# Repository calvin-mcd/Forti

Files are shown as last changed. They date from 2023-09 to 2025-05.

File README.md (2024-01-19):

# Førti

The Førti pcb (40 in Norwegian) is a 13u 40% pcb with full basekit support for the upcoming Førti keyboard case created and designed by xonuss and xezioh that is based on [Geon's F1-8x](https://geon.works/pages/f1-8x). The pcb takes its layout and design cues from the [oxymoron](https://imgur.com/a/UKyKxDe), [bully](https://www.cbkbd.com/product/bully) and [ttocyobitna](https://trashman.wiki/keyboards/ttocyobitna) amongst others. It's a stm32 based pcb for low cost, good performance.

## Layout

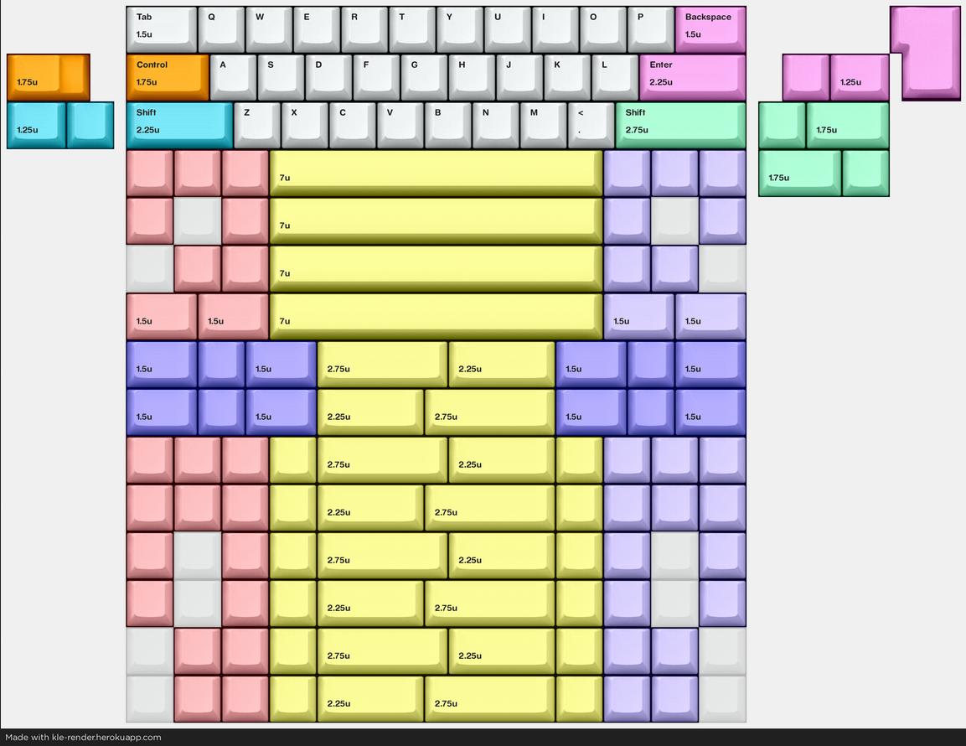
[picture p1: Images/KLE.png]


[Link](http://www.keyboard-layout-editor.com/#/gists/abf1199a554d2e1b5c349f9fdb908042)

## Case

WIP, design by xonuss

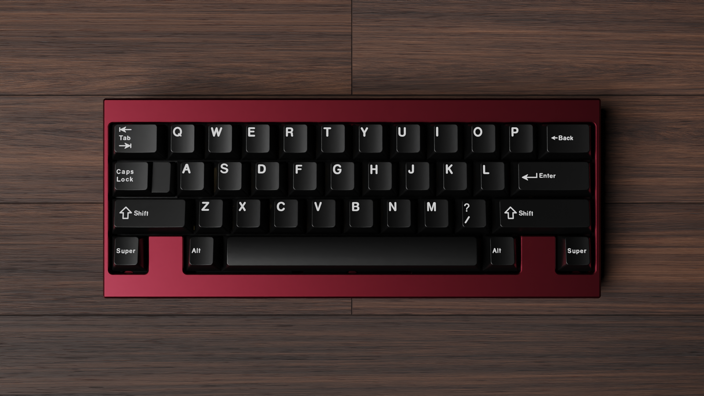
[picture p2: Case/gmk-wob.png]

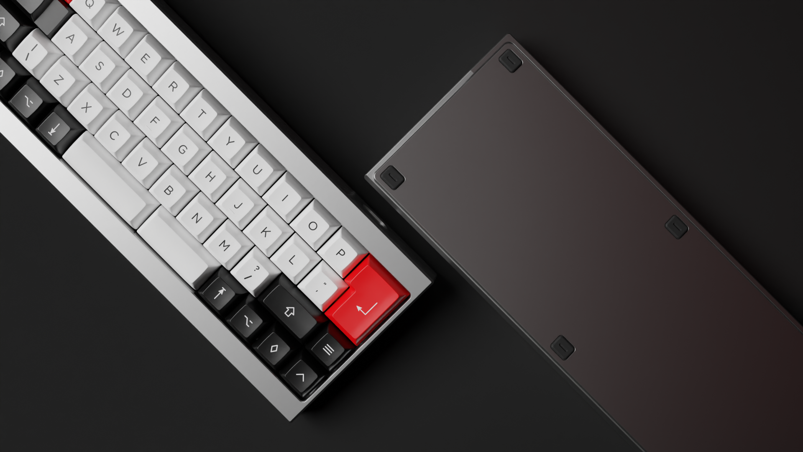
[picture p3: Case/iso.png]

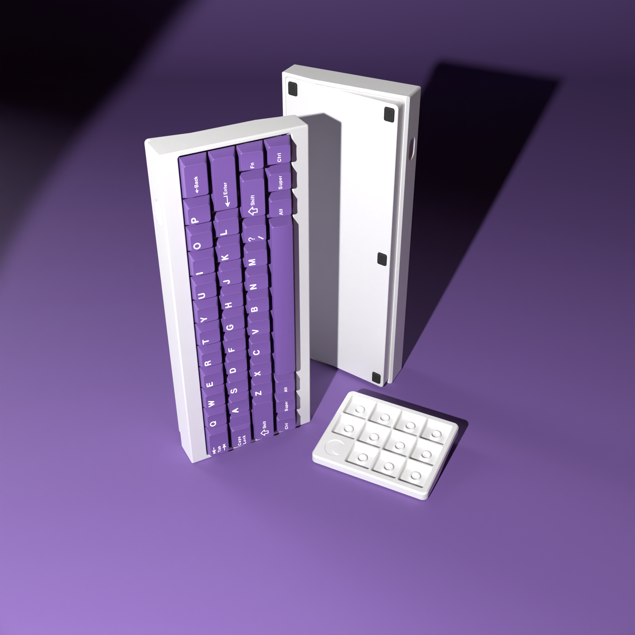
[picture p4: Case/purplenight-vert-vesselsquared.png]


## Todo

- [X] order & test pcb
- [X] create firmware
- [X] order & test case
- [ ] revise mx pcb
- [ ] create HS & EC pcbs (work-in-progress)

## Disclaimer

Please note that this project is a work in progress with no guarantees of a working outcome. No-one involved in this project is responsible for any usage issues that may arise. However, feel free to edit, modify and otherwise utilise these files.

## License

Shield: 

This work is licensed under a  
[Creative Commons Attribution-NonCommercial-ShareAlike 4.0 International License](http://creativecommons.org/licenses/by-nc-sa/4.0/).



## Credits

Big thanks to xonuss and xezioh for letting me join this awesome collaboration!	

As always big thanks to the many people who helped and inspired this board!

Any questions, contact Calvin0563 on Discord.

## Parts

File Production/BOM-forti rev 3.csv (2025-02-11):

Comment | Designator | Footprint | LCSC | Quantity
SKQGABE010 | SW1 | SW_SPST_SKQG_WithoutStem | C115351 | 1
100nF | C4,C5,C6,C7,C8,C9 | C_0603_1608Metric | C14663 | 6
5k1 | R1,R2 | R_0603_1608Metric | C14677 | 2
1uF | C1,C2 | C_0603_1608Metric | C15849 | 2
USB_C_Receptacle_USB2.0 | J1 | USB_C_Receptacle_HRO_TYPE-C-31-M-12 | C165948 | 1
10k | R3 | R_0603_1608Metric | C2139679 | 1
USBLC6-2SC6 | U1 | SOT-23-6 | C2827654 | 1
XC6206PxxxMR-Regulator_Linear | U3 | SOT-23 | C5446 | 1
D_Small | D1,D10,D11,D12,D13,D14,D15,D16,D17,D18,D19,D2,D20,D21,D22,D23,D24,D25,D26,D27,D28,D29,D3,D30,D31,D32,D33,D34,D35,D36,D37,D38,D39,D4,D40,D41,D42,D43,D44,D45,D46,D47,D5,D6,D7,D8,D9 | D_SOD-123F | C64898 | 47
500mA | F1 | Fuse_1206_3216Metric | C70076 | 1
SMF9.0CA | D_PWR1 | D_SOD-123 | C707469 | 1
STM32F072C8Tx | U2 | LQFP-48_7x7mm_P0.5mm | C80488 | 1
10uF | C3 | C_0603_1608Metric | C96446 | 1

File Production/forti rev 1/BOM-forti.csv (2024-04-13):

Comment | Designator | Footprint | LCSC
SKQGABE010 | SW1 | SW_SPST_SKQG_WithoutStem | C115351
100nF | C10,C4,C5,C6,C7,C8,C9 | C_0603_1608Metric | C14663
5k1 | R1,R2 | R_0603_1608Metric | C14677
1uF | C1,C2 | C_0603_1608Metric | C15849
USB_C_Receptacle_USB2.0 | J1 | USB_C_Receptacle_HRO_TYPE-C-31-M-12 | C165948
10k | R3 | R_0603_1608Metric | C2139679
USBLC6-2SC6 | U1 | SOT-23-6 | C2827654
XC6206PxxxMR-Regulator_Linear | U3 | SOT-23 | C5446
D_Small | D1,D10,D11,D12,D13,D14,D15,D16,D17,D18,D19,D2,D20,D21,D22,D23,D24,D25,D26,D27,D28,D29,D3,D30,D31,D32,D33,D34,D35,D36,D37,D38,D39,D4,D40,D41,D42,D43,D44,D45,D46,D47,D5,D6,D7,D8,D9 | D_SOD-123F | C64898
500mA | F1 | Fuse_1206_3216Metric | C70076
SMF9.0CA | D_PWR1 | D_SOD-123 | C707469
74AHCT1G125 | U4 | TSOT-23-5 | C7468
STM32F072C8Tx | U2 | LQFP-48_7x7mm_P0.5mm | C80488
10uF | C3 | C_0603_1608Metric | C96446
WS2812_2020 | LED1,LED10,LED11,LED12,LED13,LED14,LED15,LED16,LED17,LED18,LED2,LED3,LED4,LED5,LED6,LED7,LED8,LED9 | LED_WS2812_2020 | C965555

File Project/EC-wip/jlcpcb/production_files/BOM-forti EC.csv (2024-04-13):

Comment | Designator | Footprint | LCSC
1k | R23 | R_0402_1005Metric | C11702
STM32F401CBUx | U8 | QFN-48-1EP_7x7mm_P0.5mm_EP5.6x5.6mm | C118825
100nF | C12 | C_0603_1608Metric | C14663
1uF | C1 | C_0603_1608Metric | C14664
5k1 | R1,R2 | R_0603_1608Metric | C14677
220pF NP0 | C4 | C_0402_1005Metric | C1530
USB_C_Receptacle_USB2.0 | J2 | USB_C_Receptacle_HRO_TYPE-C-31-M-12 | C165948
4.7u | C16 | C_0402_1005Metric | C23733
100 | R19,R20,R21,R22 | R_0402_1005Metric | C25076
100k | R11,R12,R13,R14,R15,R16,R17,R18,R4,R5,R6,R7,R8,R9 | R_0402_1005Metric | C25741
10k | R24,R25,R27 | R_0402_1005Metric | C25744
USBLC6-2SC6 | U1 | SOT-23-6 | C2827654
100n | C10,C15,C17,C18,C19,C20,C21,C3 | C_0402_1005Metric | C307331
OPA354 | U3 | SOT-23-5 | C36384
1uF | C2,C22 | C_0603_1608Metric | C52923
XC6206PxxxMR-Regulator_Linear | U2 | SOT-23 | C5446
74HC4051 | U5,U7 | TSSOP16 | C5645
500mA | F1 | Fuse_1206_3216Metric | C70076
SMF9.0CA | D_PWR1 | D_SOD-123 | C707469
74AHCT1G125 | U4 | TSOT-23-5 | C7468
8 MHz | Y1 | Resonator_SMD_Murata_CSTxExxV-3Pin_3.0x1.1mm | C907975
WS2812_2020 | LED1,LED15,LED16,LED17,LED18,LED19,LED2,LED20,LED21,LED22,LED23,LED24,LED25,LED26,LED27,LED3,LED30,LED31 | LED_WS2812_2020 | C965555

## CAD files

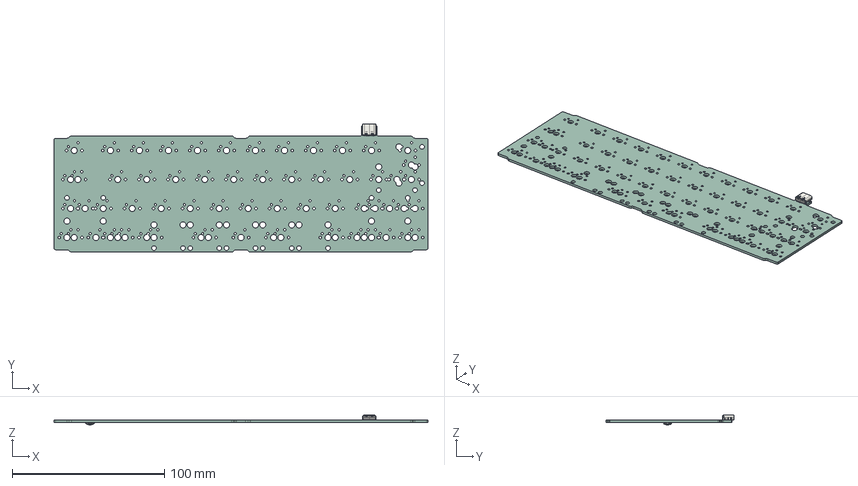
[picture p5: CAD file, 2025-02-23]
Project/forti rev 3.step
245.7 x 84.1 x 6.55 mm
USB_C_Receptacle_16P_TopMnt_Horizontal_GCT_USB4105-xx-A
SW_SPST_TL3342
forti rev 3_PCB

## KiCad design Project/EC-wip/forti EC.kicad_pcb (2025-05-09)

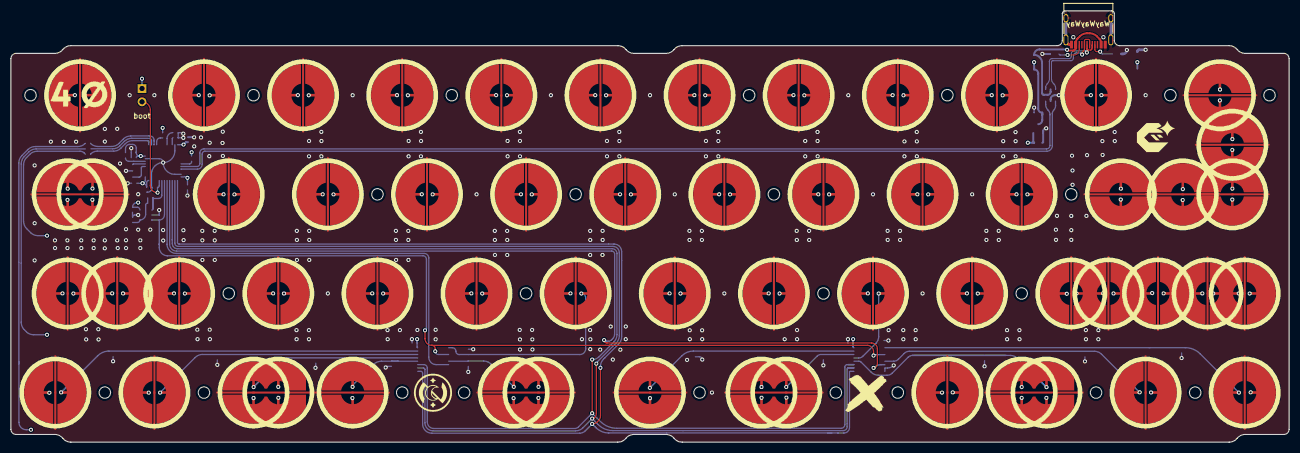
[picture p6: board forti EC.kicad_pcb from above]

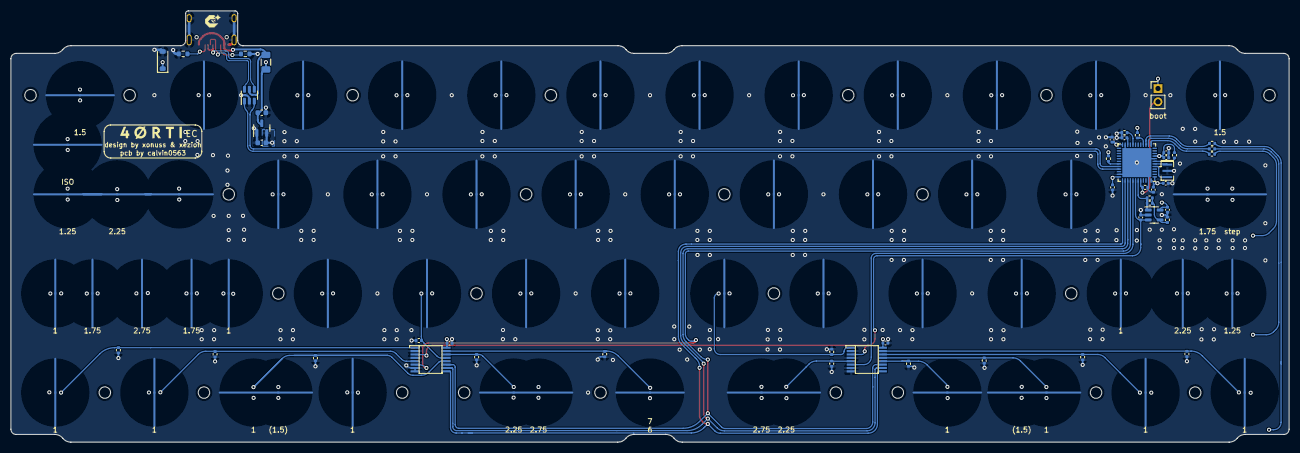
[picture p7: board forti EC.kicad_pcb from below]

Board: 4 copper layers, 245.7 x 82.9 mm, 124 parts (48 on the bottom side), 45 nets.

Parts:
C1, C2: 1uF; C_0603_1608Metric
C3, C10, C15, C17, C18, C19, C20, C21: 100n; C_0402_1005Metric
C4: 220pF NP0; C_0402_1005Metric
C16: 4.7u; C_0402_1005Metric
C22: 1u; C_0402_1005Metric
D_PWR1: SMF9.0CA; D_SOD-123
F1: 500mA; Fuse_1206_3216Metric
H1, H2, H3, H4, H5, H6, H7, H8, H9, H10, H11, H12, H13, H14, H15, H16, H17, H18, H19, H20, H21, H22, H23, H24: MountingHole; HOLE_M2
J2: USB_C_Receptacle_USB2.0; USB_C_Receptacle_HRO_TYPE-C-31-M-12
R1, R2: 5k1; R_0603_1608Metric
R4, R5, R6, R7, R8, R9, R11, R12, R13, R14, R15, R16, R17, R18: 100k; R_0402_1005Metric
R19, R20, R21, R22: 100; R_0402_1005Metric
R23: 1k; R_0402_1005Metric
R24, R25, R27: 10k; R_0402_1005Metric
R26: DNP; R_0402_1005Metric
SW1: BOOT0; PinHeader_1x02_P2.54mm_Vertical
SW_EC1, SW_EC2, SW_EC3, SW_EC4, SW_EC5, SW_EC6, SW_EC7, SW_EC8, SW_EC9, SW_EC10, SW_EC11, SW_EC12, SW_EC14, SW_EC15, SW_EC16, SW_EC17, SW_EC18, SW_EC19, SW_EC20, SW_EC21, SW_EC22, SW_EC24, SW_EC25, SW_EC26, SW_EC27, SW_EC28, SW_EC29, SW_EC30, SW_EC31, SW_EC32, SW_EC33, SW_EC34, SW_EC50: Topre; ecs_pad_1U_no_ring
SW_EC13: stepped; ecs_pad_no_ring_stepped&normal
SW_EC23: Topre; ecs_pad_1U_no_ring_1u_edge_cut
SW_EC35, SW_EC36: 1u, 175u; ecs_pad_no_ring_1u1.75u
SW_EC37, SW_EC38, SW_EC40, SW_EC44, SW_EC46, SW_EC47: 1u; ecs_pad_1U_no_ring
SW_EC39, SW_EC45: stepped; ecs_pad_no_ring_stepped&normal_cut
SW_EC41, SW_EC43: split; ecs_pad_no_ring_stepped&normal
SW_EC42: 6u 7u; ecs_pad_1U_no_ring
SW_EC48: ISO; ecs_pad_1U_no_ring
SW_EC49: ansi; ecs_pad_1U_no_ring_1u_edge_cut
SW_EC52: 275u; ecs_pad_1U_no_ring
U1: USBLC6-2SC6; SOT-23-6
U2: XC6206PxxxMR-Regulator_Linear; SOT-23
U3: OPA354; SOT-23-5
U5, U7: 74HC4051; TSSOP16
U8: STM32F401CBUx; QFN-48-1EP_7x7mm_P0.5mm_EP5.6x5.6mm
Y1: 8 MHz; Resonator_SMD_Murata_CSTxExxV-3Pin_3.0x1.1mm

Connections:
+5V: C1.2, D_PWR1.1 (A1), F1.2, U2.3 (VI)
/CC1: J2.A5 (CC1), R1.1
/CC2: J2.B5 (CC2), R2.1
ADC: R6.1, R26.1, U3.1, U8.43 (PB7)
AMUX_SEL_0: U5.11 (S0), U7.11 (S0), U8.39 (PB3)
AMUX_SEL_1: U5.10 (S1), U7.10 (S1), U8.38 (PA15)
AMUX_SEL_2: U5.9 (S2), U7.9 (S2), U8.37 (PA14)
APLEX_EN_PIN_0: U5.6 (~E), U8.41 (PB5)
APLEX_EN_PIN_1: U7.6 (~E), U8.40 (PB4)
APLEX_OUT_PIN_0: C4.1, U3.3 (+), U5.3 (A), U7.3 (A), U8.42 (PB6)
BOOT0: R27.1, SW1.2 (B), U8.44 (BOOT0)
BOOT1: R25.2, U8.20 (PB2)
COL0: R7.1, SW_EC1.1, SW_EC13.1, SW_EC25.1, SW_EC37.1, SW_EC50.1, U5.15 (A2)
COL1: R5.1, SW_EC2.1, SW_EC14.1, SW_EC26.1, SW_EC38.1, U5.14 (A1)
COL2: R4.1, SW_EC3.1, SW_EC15.1, SW_EC27.1, SW_EC39.2, U5.13 (A0)
COL3: R8.1, SW_EC4.1, SW_EC16.1, SW_EC28.1, SW_EC40.1, U5.12 (A3)
COL4: R18.1, SW_EC5.1, SW_EC17.1, SW_EC29.1, SW_EC41.1, U5.5 (A5)
COL5: R9.1, SW_EC6.1, SW_EC18.1, SW_EC30.1, U5.1 (A4)
COL6: R13.1, SW_EC7.1, SW_EC19.1, SW_EC31.1, SW_EC42.1, U7.15 (A2)
COL7: R12.1, SW_EC8.1, SW_EC20.1, SW_EC32.1, SW_EC43.1, U7.14 (A1)
COL8: R11.1, SW_EC9.1, SW_EC21.1, SW_EC33.1, SW_EC44.1, U7.13 (A0)
COL9: R14.1, SW_EC10.1, SW_EC22.1, SW_EC34.1, SW_EC45.2, U7.12 (A3)
COL10: R16.1, SW_EC11.1, SW_EC23.2, SW_EC35.2, SW_EC46.1, U7.5 (A5)
COL11: R15.1, SW_EC12.1, SW_EC24.1, SW_EC36.1, SW_EC36.3, SW_EC47.1, SW_EC48.1, SW_EC49.1, SW_EC52.2, U7.1 (A4)
D_N: U1.3 (I/O2), U8.32 (PA11)
D_P: U1.1 (I/O1), U8.33 (PA12)
D_USB_N: J2.A7 (D-), J2.B7 (D-), U1.4 (I/O2)
D_USB_P: J2.A6 (D+), J2.B6 (D+), U1.6 (I/O1)
GND: C1.1, C2.1, C3.1, C4.2, C10.2, C15.2, C16.2, C17.2, C18.2, C19.2, C20.2, C21.2, C22.2, D_PWR1.2 (A2), J2.A1 (GND), J2.A12 (GND), J2.B1 (GND), J2.B12 (GND), J2.S1 (SHIELD), R1.2, R2.2, R4.2, R5.2, R7.2, R8.2, R9.2, R11.2, R12.2, R13.2, R14.2, R15.2, R16.2, R18.2, R23.2, R25.1, R27.2, SW_EC1.3 (SG), SW_EC2.3 (SG), SW_EC3.3 (SG), SW_EC4.3 (SG), SW_EC5.3 (SG), SW_EC6.3 (SG), SW_EC7.3 (SG), SW_EC8.3 (SG), SW_EC9.3 (SG), SW_EC10.3 (SG), SW_EC11.3 (SG), SW_EC12.3 (SG), SW_EC13.3 (SG), SW_EC14.3 (SG), SW_EC15.3 (SG), SW_EC16.3 (SG), SW_EC17.3 (SG), SW_EC18.3 (SG), SW_EC19.3 (SG), SW_EC20.3 (SG), SW_EC21.3 (SG), SW_EC22.3 (SG), SW_EC23.3 (SG), SW_EC24.3 (SG), SW_EC25.3 (SG), SW_EC26.3 (SG), SW_EC27.3 (SG), SW_EC28.3 (SG), SW_EC29.3 (SG), SW_EC30.3 (SG), SW_EC31.3 (SG), SW_EC32.3 (SG), SW_EC33.3 (SG), SW_EC34.3 (SG), SW_EC35.4 (SG), SW_EC36.4 (SG), SW_EC37.3 (SG), SW_EC38.3 (SG), SW_EC39.3 (SG), SW_EC40.3 (SG), SW_EC41.3 (SG), SW_EC42.3 (SG), SW_EC43.3 (SG), SW_EC44.3 (SG), SW_EC45.3 (SG), SW_EC46.3 (SG), SW_EC47.3 (SG), SW_EC48.3 (SG), SW_EC49.3 (SG), SW_EC50.3 (SG), SW_EC52.3 (SG), U1.2 (GND), U2.1 (GND), U3.2 (V-), U5.2 (A6), U5.4 (A7), U5.7 (VEE), U5.8 (GND), U7.2 (A6), U7.4 (A7), U7.7 (VEE), U7.8 (GND), U8.8 (VSSA), U8.23 (VSS), U8.35 (VSS), U8.47 (VSS), U8.49 (VSS), Y1.2
NRST: R24.2, U8.7 (NRST)
unnamed: R6.2, R23.1, R26.2, U3.4 (-)
unnamed: R19.1, U8.13 (PA3)
unnamed: R20.1, U8.14 (PA4)
unnamed: R21.2, U8.15 (PA5)
unnamed: R22.2, U8.16 (PA6)
unnamed: R17.1, U8.31 (PA10)
unnamed: C16.1, U8.22 (VCAP1)
ROW0: R22.1, SW_EC1.2, SW_EC2.2, SW_EC3.2, SW_EC4.2, SW_EC5.2, SW_EC6.2, SW_EC7.2, SW_EC8.2, SW_EC9.2, SW_EC10.2, SW_EC11.2, SW_EC12.2
ROW1: R19.2, SW_EC13.2, SW_EC14.2, SW_EC15.2, SW_EC16.2, SW_EC17.2, SW_EC18.2, SW_EC19.2, SW_EC20.2, SW_EC21.2, SW_EC22.2, SW_EC23.1, SW_EC24.2, SW_EC48.2, SW_EC49.2
ROW2: R20.2, SW_EC25.2, SW_EC26.2, SW_EC27.2, SW_EC28.2, SW_EC29.2, SW_EC30.2, SW_EC31.2, SW_EC32.2, SW_EC33.2, SW_EC34.2, SW_EC35.1, SW_EC35.3, SW_EC36.2, SW_EC50.2, SW_EC52.1
ROW3: R21.1, SW_EC37.2, SW_EC38.2, SW_EC39.1, SW_EC40.2, SW_EC41.2, SW_EC42.2, SW_EC43.2, SW_EC44.2, SW_EC45.1, SW_EC46.2, SW_EC47.2
VBAT: C2.2, C3.2, C10.1, C15.1, C17.1, C18.1, C19.1, C20.1, C21.1, C22.1, R17.2, R24.1, SW1.1 (A), U2.2 (VO), U3.5 (V+), U5.16 (VCC), U7.16 (VCC), U8.1 (VBAT), U8.9 (VREF+), U8.24 (VDD), U8.36 (VDD), U8.48 (VDD)
VBUS: F1.1, J2.A4 (VBUS), J2.A9 (VBUS), J2.B4 (VBUS), J2.B9 (VBUS), U1.5 (VBUS)
XTAL0: U8.5 (PH0), Y1.3
XTAL1: U8.6 (PH1), Y1.1

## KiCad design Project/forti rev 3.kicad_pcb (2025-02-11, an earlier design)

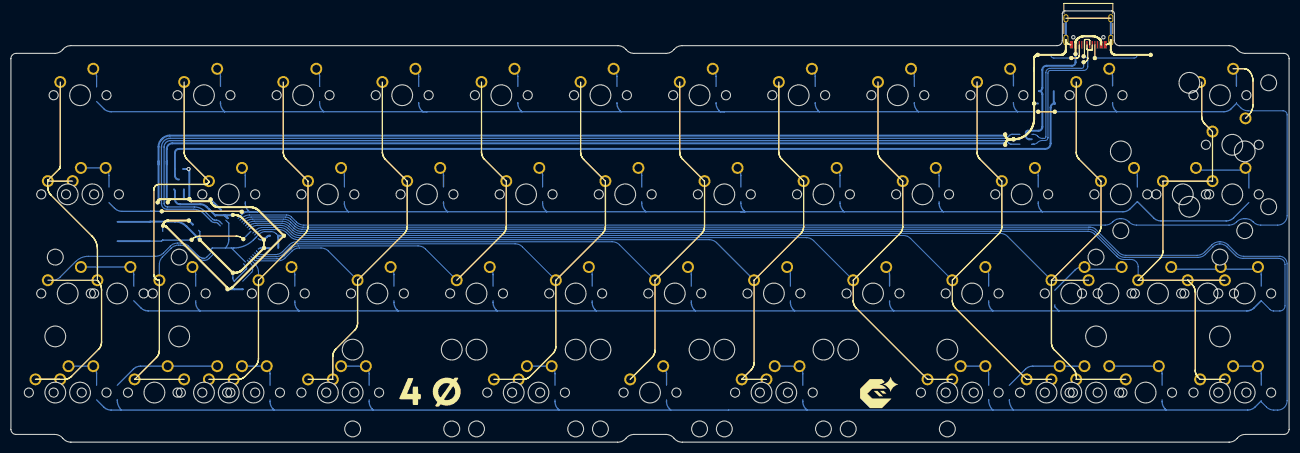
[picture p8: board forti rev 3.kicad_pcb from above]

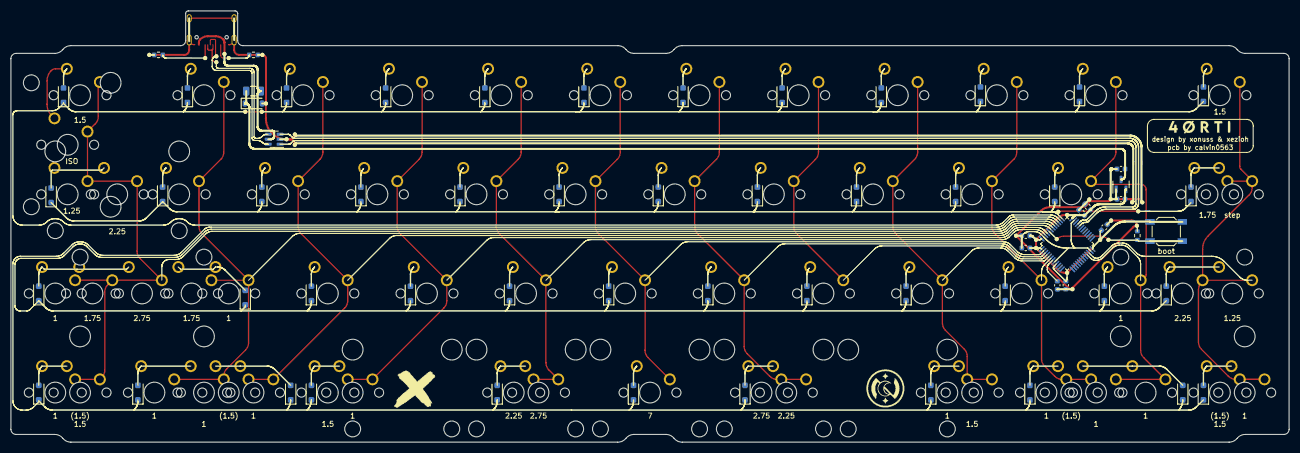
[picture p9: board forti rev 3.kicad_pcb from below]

Board: 2 copper layers, 245.7 x 82.9 mm, 139 parts (65 on the bottom side), 75 nets.

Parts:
C1, C2: 1uF; C_0603_1608Metric
C3: 10uF; C_0603_1608Metric
C4, C5, C6, C7, C8, C9: 100nF; C_0603_1608Metric
D1, D2, D3, D4, D5, D6, D7, D8, D9, D10, D11, D12, D13, D14, D15, D16, D17, D18, D19, D20, D21, D22, D23, D24, D25, D26, D27, D28, D29, D30, D31, D32, D33, D34, D35, D36, D37, D38, D39, D40, D41, D42, D43, D44, D45, D46, D47: D_Small; D_SOD-123F
D_PWR1: SMF9.0CA; D_SOD-123
F1: 500mA; Fuse_1206_3216Metric
ISO1: MX_stab; STAB_MX_ISO-ROT
J1: USB_C_Receptacle_USB2.0; USB_C_Receptacle_HRO_TYPE-C-31-M-12
MX1, MX12, MX40, MX44, MX46, MX49, MX51, MX55: MX_SW_HS; SW_MX_1.5u
MX2, MX3, MX4, MX5, MX6, MX7, MX8, MX9, MX10, MX11, MX14, MX15, MX16, MX17, MX18, MX19, MX20, MX21, MX22, MX23, MX26, MX27, MX28, MX29, MX30, MX31, MX32, MX33, MX34, MX35, MX38, MX39, MX41, MX42, MX43, MX45, MX47, MX48, MX50, MX52, MX53, MX54: MX_SW_HS; SW_MX_1u
MX13, MX36, MX37: MX_SW_HS; SW_MX_1.75u
MX24, MX25: MX_SW_HS; SW_MX_1.25u
MXISO1: MX_SW_HS; SW_MX_1u
MXcaps1: MX_SW_HS; SW_MX_1.75u_STP_1.25
MXenter2.1: MX_SW_HS; SW_MX_1u
MXshift2.1, MXshift2.2: MX_SW_HS; SW_MX_1u
MXsplit2.1, MXsplit2.2, MXsplit2.25(1)1, MXsplit2.75(1)1: MX_SW_HS; SW_MX_1u
R1, R2: 5k1; R_0603_1608Metric
R3: 10k; R_0603_1608Metric
S1, S4: 225; STAB_MX_2.25u
S2: 7; STAB_MX_7u
S3, S5: 275; STAB_MX_2.75u
SW1: SKQGABE010; SW_SPST_SKQG_WithoutStem
U1: USBLC6-2SC6; SOT-23-6
U2: STM32F072C8Tx; LQFP-48_7x7mm_P0.5mm
U3: XC6206PxxxMR-Regulator_Linear; SOT-23
enter2.1: MX_stab; STAB_MX_2.25u
shift2.1: MX_stab; STAB_MX_2.75u
shift2.2: MX_stab; STAB_MX_2.25u

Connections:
+3V3: C2.2, C3.1, C4.1, C5.1, C6.1, C7.1, C8.1, SW1.1, U2.1 (VBAT), U2.9 (VDDA), U2.24 (VDD), U2.36 (VDDIO2), U2.48 (VDD), U3.2 (VO)
+5V: C1.2, D_PWR1.1 (A1), F1.2, U3.3 (VI)
/CC1: J1.A5 (CC1), R1.1
/CC2: J1.B5 (CC2), R2.1
BOOT0: R3.1, SW1.2, U2.44 (BOOT0)
COL0: MX1.1, MX13.1, MX25.1, MX39.1, MX40.1, MXcaps1.1, MXshift2.1.1, U2.22 (PB11)
COL1: MX2.1, MX14.1, MX26.1, MX41.1, MX42.1, U2.21 (PB10)
COL2: MX3.1, MX15.1, MX27.1, MX43.1, MX44.1, U2.6 (PF1)
COL3: MX4.1, MX16.1, MX28.1, MX45.1, MX46.1, U2.5 (PF0)
COL4: MX5.1, MX17.1, MX29.1, U2.4 (PC15)
COL5: MX6.1, MX18.1, MX30.1, MXsplit2.1.1, MXsplit2.25(1)1.1, U2.3 (PC14)
COL6: MX7.1, MX19.1, MX31.1, MX47.1, U2.2 (PC13)
COL7: MX8.1, MX20.1, MX32.1, MXsplit2.2.1, MXsplit2.75(1)1.1, U2.46 (PB9)
COL8: MX9.1, MX21.1, MX33.1, MX48.1, MX49.1, U2.45 (PB8)
COL9: MX10.1, MX22.1, MX34.1, MX50.1, MX51.1, U2.43 (PB7)
COL10: MX11.1, MX23.1, MX35.1, MX36.1, MX52.1, MX53.1, U2.42 (PB6)
COL11: MX12.1, MX24.1, MX37.1, MX38.1, MX54.1, MX55.1, MXISO1.1, MXenter2.1.1, MXshift2.2.1, U2.41 (PB5)
D_N: U1.3 (I/O2), U2.32 (PA11)
D_P: U1.1 (I/O1), U2.33 (PA12)
D_USB_N: J1.A7 (D-), J1.B7 (D-), U1.4 (I/O2)
D_USB_P: J1.A6 (D+), J1.B6 (D+), U1.6 (I/O1)
GND: C1.1, C2.1, C3.2, C4.2, C5.2, C6.2, C7.2, C8.2, C9.2, D_PWR1.2 (A2), J1.A1 (GND), J1.A12 (GND), J1.B1 (GND), J1.B12 (GND), J1.S1 (SHIELD), R1.2, R2.2, R3.2, U1.2 (GND), U2.8 (VSSA), U2.23 (VSS), U2.35 (VSS), U2.47 (VSS), U3.1 (GND)
NRST: C9.1, U2.7 (NRST)
unnamed: D1.2 (A), MX1.2
unnamed: D2.2 (A), MX2.2
unnamed: D3.2 (A), MX3.2
unnamed: D4.2 (A), MX4.2
unnamed: D5.2 (A), MX5.2
unnamed: D6.2 (A), MX6.2
unnamed: D7.2 (A), MX7.2
unnamed: D8.2 (A), MX8.2
unnamed: D9.2 (A), MX9.2
unnamed: D10.2 (A), MX10.2
unnamed: D11.2 (A), MX11.2
unnamed: D12.2 (A), MX12.2, MXISO1.2
unnamed: D13.2 (A), MX13.2, MXcaps1.2
unnamed: D14.2 (A), MX14.2
unnamed: D15.2 (A), MX15.2
unnamed: D16.2 (A), MX16.2
unnamed: D17.2 (A), MX17.2
unnamed: D18.2 (A), MX18.2
unnamed: D19.2 (A), MX19.2
unnamed: D20.2 (A), MX20.2
unnamed: D21.2 (A), MX21.2
unnamed: D22.2 (A), MX22.2
unnamed: D23.2 (A), MX23.2
unnamed: D24.2 (A), MX24.2, MXenter2.1.2
unnamed: D25.2 (A), MX25.2, MXshift2.1.2
unnamed: D26.2 (A), MX26.2
unnamed: D27.2 (A), MX27.2
unnamed: D28.2 (A), MX28.2
unnamed: D29.2 (A), MX29.2
unnamed: D30.2 (A), MX30.2
unnamed: D31.2 (A), MX31.2
unnamed: D32.2 (A), MX32.2
unnamed: D33.2 (A), MX33.2
unnamed: D34.2 (A), MX34.2
unnamed: D35.2 (A), MX35.2, MX36.2
unnamed: D36.2 (A), MX37.2, MX38.2, MXshift2.2.2
unnamed: D37.2 (A), MX39.2, MX40.2
unnamed: D38.2 (A), MX41.2, MX42.2
unnamed: D39.2 (A), MX43.2, MX44.2
unnamed: D40.2 (A), MX45.2, MX46.2
unnamed: D41.2 (A), MXsplit2.1.2, MXsplit2.25(1)1.2
unnamed: D42.2 (A), MX47.2
unnamed: D43.2 (A), MXsplit2.2.2, MXsplit2.75(1)1.2
unnamed: D44.2 (A), MX48.2, MX49.2
unnamed: D45.2 (A), MX50.2, MX51.2
unnamed: D46.2 (A), MX52.2, MX53.2
unnamed: D47.2 (A), MX54.2, MX55.2
ROW0: D1.1 (K), D2.1 (K), D3.1 (K), D4.1 (K), D5.1 (K), D6.1 (K), D7.1 (K), D8.1 (K), D9.1 (K), D10.1 (K), D11.1 (K), D12.1 (K), U2.38 (PA15)
ROW1: D13.1 (K), D14.1 (K), D15.1 (K), D16.1 (K), D17.1 (K), D18.1 (K), D19.1 (K), D20.1 (K), D21.1 (K), D22.1 (K), D23.1 (K), D24.1 (K), U2.37 (PA14)
ROW2: D25.1 (K), D26.1 (K), D27.1 (K), D28.1 (K), D29.1 (K), D30.1 (K), D31.1 (K), D32.1 (K), D33.1 (K), D34.1 (K), D35.1 (K), D36.1 (K), U2.40 (PB4)
ROW3: D37.1 (K), D38.1 (K), D39.1 (K), D40.1 (K), D41.1 (K), D42.1 (K), D43.1 (K), D44.1 (K), D45.1 (K), D46.1 (K), D47.1 (K), U2.39 (PB3)
VBUS: F1.1, J1.A4 (VBUS), J1.A9 (VBUS), J1.B4 (VBUS), J1.B9 (VBUS), U1.5 (VBUS)

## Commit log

2023-06-04 first full design
    [mekanisk-40.kicad_pcb, mekanisk-40.kicad_sch]
2023-06-07 slight routing cleanup
    [mekanisk-40.kicad_pcb, mekanisk-40.kicad_sch]
2023-06-09 component placement
    [mekanisk-40.kicad_pcb]
2023-06-30 created 13u & 14u keyboard versions
    [mekanisk-40 14U.kicad_pcb, mekanisk-40 14U.kicad_sch, mekanisk-40.kicad_pcb]
2023-07-02 changed routing and reset button placement on 13u
    [mekanisk-40 14U.kicad_pcb, mekanisk-40.kicad_pcb]
2023-07-13 minimal gnd fill, added jst pico footprints
    [mekanisk-40.kicad_pcb, mekanisk-40.kicad_sch]
2023-08-05 routing update
    [mekanisk-40.kicad_pcb]
2023-08-24 slight routing change, necessary?
    [mekanisk-40.kicad_pcb, mekanisk-40.kicad_sch]
2023-09-11 renaming project
    [mekanical.kicad_pcb, mekanical.kicad_sch]
2023-09-24 created production files
    [BOM-mekanical - Kopie.csv, BOM-mekanical.csv, mekanical HS.kicad_sch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]
2023-10-01 fresh production files
    [BOM-mekanical - Kopie.csv, BOM-mekanical.csv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]
2023-10-08 revision, small changes
    [BOM-mekanical.csv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]
2023-10-10 update readme, added production files
    [OK T-2D6W637981A-5sets-BOM-mekanical(2023-10-05).xls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]
2023-10-10 fresh gerbers (small routing aeshetics)
    [mekanical-B_Cu.gbr, mekanical-B_Mask.gbr, mekanical-B_Paste.gbr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]
2023-10-16 renamed project, moved HS into backup
    [forti.kicad_sch]
2023-10-22 new bottom row, proto project created, rgb revised
    [forti proto.kicad_sch, forti.kicad_sch, rgb proto.kicad_sch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]
2023-10-29 updated bottom row options on solder, started HS, EC
    [EC matrix.kicad_sch, analog.kicad_sch, forti EC.kicad_pcb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]
2023-10-31 cleaned up main folder, created separate folder for different pcb versions
    [EC matrix.kicad_sch, analog.kicad_sch, forti EC.kicad_pcb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]
2023-11-09 EC progress
    [EC matrix.kicad_sch, analog.kicad_sch, forti EC.kicad_pcb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]
2023-11-17 progress on EC version
    [EC matrix.kicad_sch, forti EC.kicad_pcb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]
2023-12-02 small changes made after left shift was discovered to be wrong
    new new edge cut for full revision though
    [BOM-forti.csv, forti EC.kicad_pcb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]
2024-01-14 EC bottom row and mounting holes
    need to double check routing 90°
    [EC matrix.kicad_sch, forti EC.kicad_pcb, plate EC.kicad_pcb]
2024-01-19 forti work
    [forti EC.kicad_pcb]
2024-01-28 backup / cleanup
    [forti.kicad_sch, plate EC.kicad_pcb, rgb.kicad_sch]
2024-04-13 two different pcb versions
    [BOM-forti EC.csv, BOM-forti GND.csv, analog.kicad_sch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]
2024-04-21 forti gnd 2?
2024-04-22 gnd revision
    [forti GND-B_Cu.gbr, forti GND-B_Mask.gbr, forti GND-B_Paste.gbr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]
2024-04-22 project cleanup
    [BOM-forti EC.csv, BOM-forti.csv, BOM-mekanical.csv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]
2024-05-05 usb revision
    no exposed copper yet
    [forti usb port.kicad_pcb]
2024-06-07 rev 3
    [BOM-forti Rev 2 Proto.csv, BOM-forti usb port.csv, BOM-forti.csv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]
2024-12-22 revision
    usb needs fix still
    [forti rev 3-B_Cu.gbr, forti rev 3-B_Mask.gbr, forti rev 3-B_Paste.gbr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]
2025-02-11 update production files v3
    [BOM-forti Rev 2 Proto.csv, BOM-forti rev 3.csv, BOM-forti.csv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]
2025-02-23 rev 3 ready for proto
    [BOM-forti GND.csv, BOM-forti rev 3.csv, BOM-forti usb port.csv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]
2025-05-09 rev 4
    [forti EC.kicad_pcb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]
